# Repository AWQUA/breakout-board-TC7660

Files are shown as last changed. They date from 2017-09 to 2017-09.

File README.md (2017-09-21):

# module-dual-supply

### This awesome little board handles a question that persistently pops up in forums: given a voltage and ground (aka a single supply), how can you get a negative voltage (aka a dual supply)? The centerpiece of this board is the awesome little TC7660 inverting DC-DC charge pump, which can easily be sourced for less than $1 in single quantities.

### This module is essentially just a breakout board for the TC7660. There are a couple of things to note when using this chip, and hence this module:

### 1. The positive voltage (V+) must be between 1.5V and 10V. If you need to handle higher voltages, the pin-equivalent TC7662 goes up to 15V but costs a little more than twice as much as the TC7660.

### 2. If, and only if, V+ is less than 3.5V then the header pin pair JP (upper-right of board layout) must be jumpered.

### 3. The capacitors should be 10uF. If you are using polarized capacitors, be very very sure to get the orientations correct.

### 4. As far as we know, the decoupling capacitor C3 is optional for the TC7660; a 2.2uF decoupling capacitor is required for the TC7662 if the input voltage has a large impedance.

### 5. Both the TC7660 and TC7662 can source up to 20mA, which is more than sufficient for running some dual-supply op amps on a single supply board.

### 6. Finally, note that the TC7660H is also available (roughly 20% for expensive than the TC7660) which has a higher switching frequency and only requires 1uF capacitors instead of 10uF capacitors.

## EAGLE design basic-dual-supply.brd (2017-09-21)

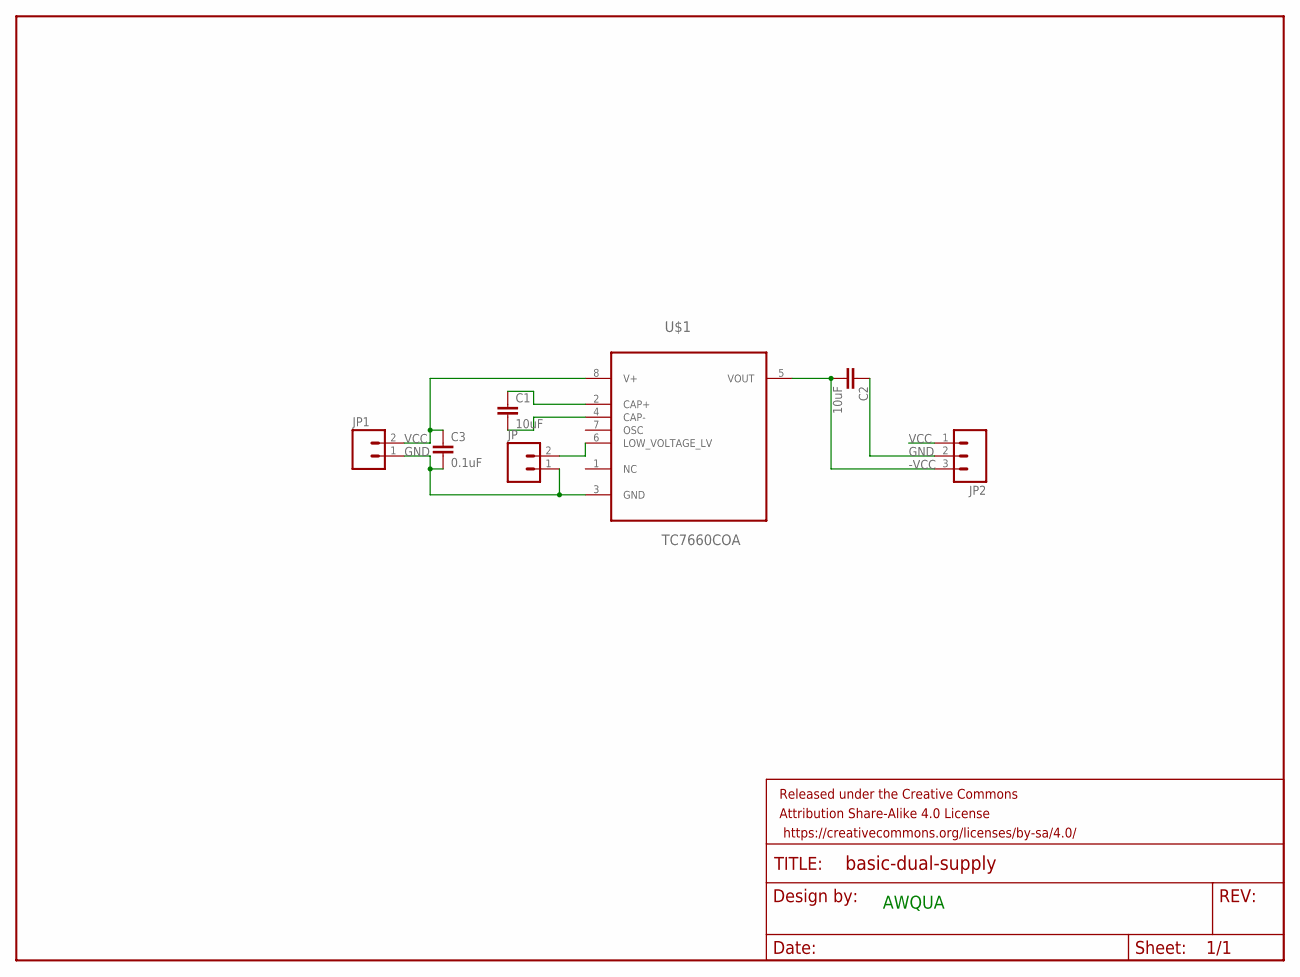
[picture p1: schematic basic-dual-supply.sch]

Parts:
C1, C2: 10uF; 0603-CAP
C3: 0.1uF; 0603-CAP
FRAME1: FRAME-LETTER; CREATIVE_COMMONS
JP, JP1: M02PTH; 1X02
JP2: M03PTH; 1X03
U$1: TC7660COA; SOIC127P600X175-8N

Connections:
-VCC: C2.2, JP2.3, U$1.5 (VOUT)
GND: C2.1, C3.2, JP.1, JP1.1, JP2.2, U$1.3 (GND)
unnamed: C1.1, U$1.2 (CAP+)
unnamed: C1.2, U$1.4 (CAP-)
unnamed: JP.2, U$1.6 (LOW_VOLTAGE_LV)
VCC: C3.1, JP1.2, JP2.1, U$1.8 (V+)

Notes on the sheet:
AWQUA

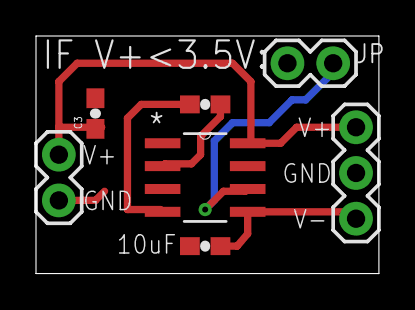
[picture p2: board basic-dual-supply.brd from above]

Board: 2 copper layers, 19.1 x 13.2 mm, 8 parts (0 on the bottom side), 6 nets.

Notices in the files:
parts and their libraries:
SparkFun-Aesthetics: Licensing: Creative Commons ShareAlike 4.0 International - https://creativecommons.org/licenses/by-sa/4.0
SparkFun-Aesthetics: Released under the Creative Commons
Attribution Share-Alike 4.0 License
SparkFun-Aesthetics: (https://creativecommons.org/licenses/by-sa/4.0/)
